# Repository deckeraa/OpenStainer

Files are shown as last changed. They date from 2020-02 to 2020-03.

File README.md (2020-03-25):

# slide-stainer

The OpenStainer is open-source, open-hardware automated slide stainer for laboratory use (e.g. histology, nanotech research).

Note: the OpenStainer is not yet released. This message will be removed from the README when the project has shipped it's 1.0 version.

## Development Mode

### Run application:
Boot an RT-PREEMPT-patched Linux distro on a Raspberry Pi.
The RT-PREEMPT patch is needed for smooth motor control since the stepper control signal is generated directly on the Pi.

To build the Rust web server (./src/main.rs),
you'll need to use Nightly Rust, due to some crates (namely Rocket) that require it:
```
rustup override set nightly
```

Then build and run the binary.
The binary must be run with sudoer priveleges since it sets thread priority to real-time for purposes of motion control.
```
cargo build && sudo ./target/debug/rmrm
```

Finally, start up the Clojurescript front-end

```
lein figwheel dev devcards
```

Figwheel will automatically push cljs changes to the browser.

Wait a bit, then browse to [http://localhost:3449](http://localhost:3449).

## Configuring the software to auto-start on Pi boot
In /etc/rc.local, place the following:
```
su -l pi /home/pi/code/slide-stainer/run.sh &
```

In /etc/xdg/lxsession/LXDE-pi/autostart, place the following:
```
chromium-browser http://localhost:8000/index.html --kiosk
```

## Production Build

```
lein clean
lein cljsbuild once min
```

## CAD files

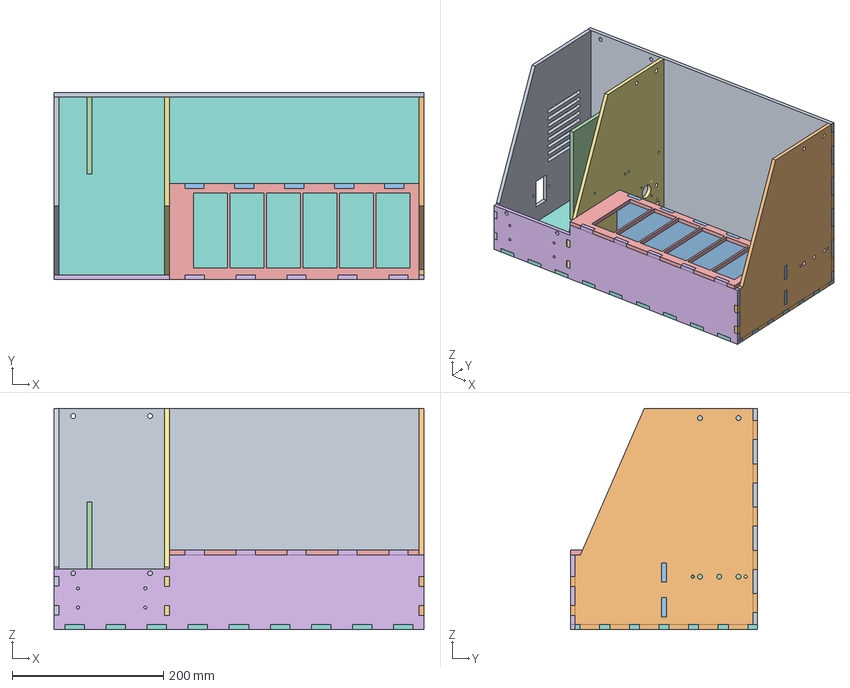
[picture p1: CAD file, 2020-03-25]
cad/frame_cut.FCStd
489.0 x 247.7 x 292.1 mm
left_plate001_tab
panel_with_rod001_tab
jar_holder_support001_tab
power_supply_retainer001_tab
jar_holder_1x007_tab
front_low_panel001_tab
panel_with_motor001_tab
bottom_panel001_tab
back_panel_body001_tab

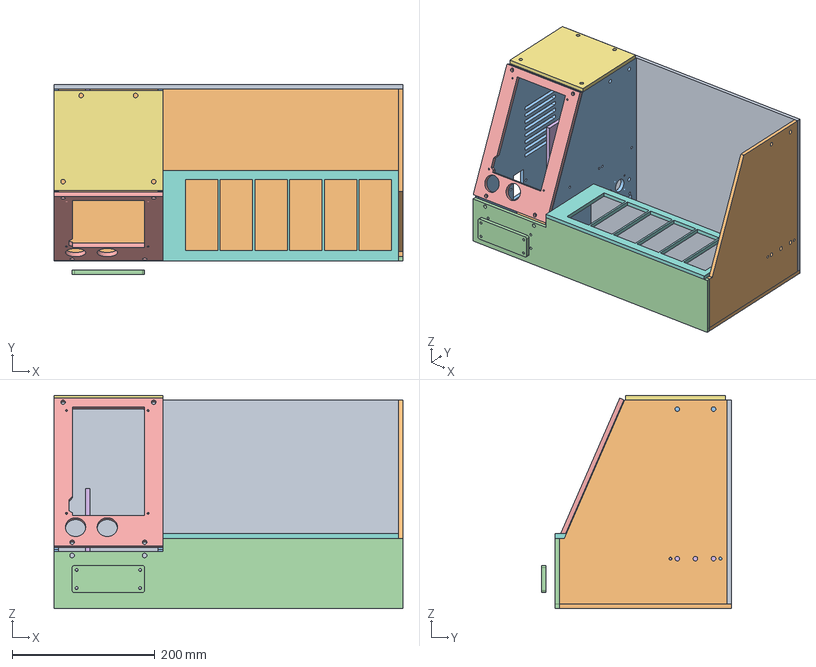
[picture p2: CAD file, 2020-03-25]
cad/frame_precut.FCStd
489.0 x 266.7 x 298.5 mm
back_panel_body
bottom_panel
panel_with_motor
front_low_panel
screen_panel_body
power_supply_retainer
cabinet_roof
jar_holder_1x6
jar_holder_support
panel_with_rod
left_plate
logo_plate

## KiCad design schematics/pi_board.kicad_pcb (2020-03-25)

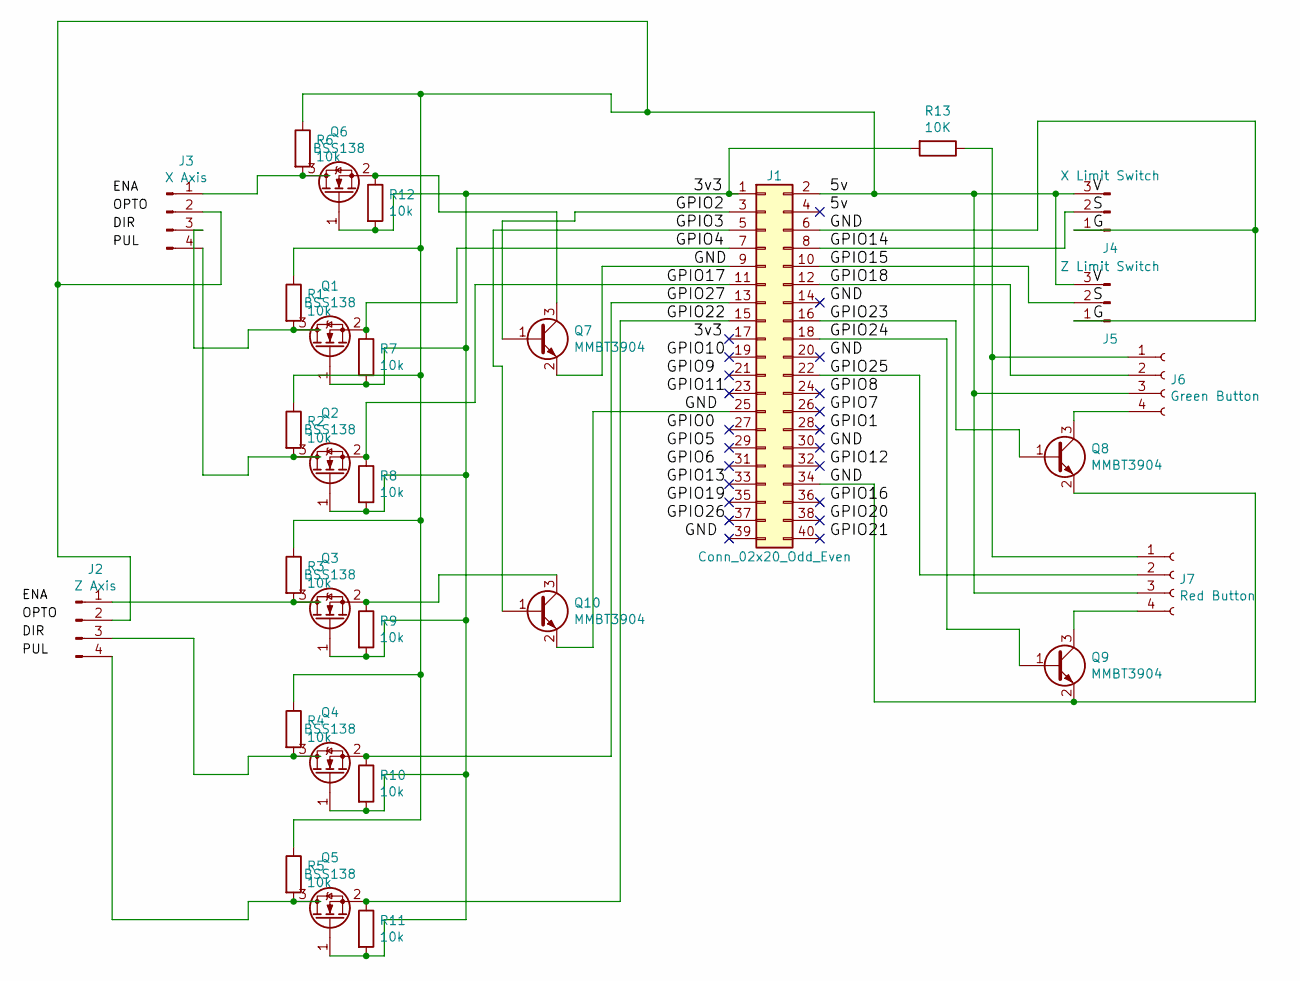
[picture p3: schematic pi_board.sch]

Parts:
J1: Conn_02x20_Odd_Even; PinHeader_2x20_P2.54mm_Vertical
J2: Z Axis; PinHeader_1x04_P2.54mm_Vertical
J3: X Axis; PinHeader_1x04_P2.54mm_Vertical
J4: X Limit Switch; PinHeader_1x03_P2.54mm_Vertical
J5: Z Limit Switch; PinHeader_1x03_P2.54mm_Vertical
J6: Green Button; PinHeader_1x04_P2.54mm_Vertical
J7: Red Button; PinHeader_1x04_P2.54mm_Vertical
Q1, Q2, Q3, Q4, Q5, Q6: BSS138; SOT-23
Q7, Q8, Q9, Q10: MMBT3904; SOT-23
R1, R2, R3, R4, R5, R6, R7, R8, R9, R10, R11, R12: 10k; R_1206_3216Metric_Pad1.42x1.75mm_HandSolder
R13: 10K; R_1206_3216Metric_Pad1.42x1.75mm_HandSolder

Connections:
/3v3: J1.1, Q1.1 (G), Q2.1 (G), Q3.1 (G), Q4.1 (G), Q5.1 (G), Q6.1 (G), R7.2, R8.2, R9.2, R10.2, R11.2, R12.2, R13.2
/5v: J1.2, J2.2, J3.2, J4.3, J5.3, J6.3, J7.3, R1.1, R2.1, R3.1, R4.1, R5.1, R6.1
/G: J1.6, J1.9, J1.25, J1.34, J4.1, J5.1, Q7.2 (E), Q8.2 (E), Q9.2 (E), Q10.2 (E)
/GPIO2: J1.3, Q7.1 (B)
/GPIO3: J1.5, Q10.1 (B)
/GPIO4: J1.7, Q1.2 (S), R7.1
/GPIO14: J1.8, J4.2
/GPIO15: J1.10, J5.2
/GPIO17: J1.11, Q2.2 (S), R8.1
/GPIO18: J1.12, J6.2
/GPIO22: J1.15, Q5.2 (S), R11.1
/GPIO23: J1.16, Q8.1 (B)
/GPIO24: J1.18, Q9.1 (B)
/GPIO25: J1.22, J7.2
/GPIO27: J1.13, Q4.2 (S), R10.1
unnamed: J2.1, Q3.3 (D), R3.2
unnamed: J2.3, Q4.3 (D), R4.2
unnamed: J2.4, Q5.3 (D), R5.2
unnamed: J3.1, Q6.3 (D), R6.2
unnamed: J3.3, Q1.3 (D), R1.2
unnamed: J3.4, Q2.3 (D), R2.2
unnamed: J6.1, J7.1, R13.1
unnamed: J6.4, Q8.3 (C)
unnamed: J7.4, Q9.3 (C)
unnamed: Q6.2 (S), Q7.3 (C), R12.1
unnamed: Q3.2 (S), Q10.3 (C), R9.1

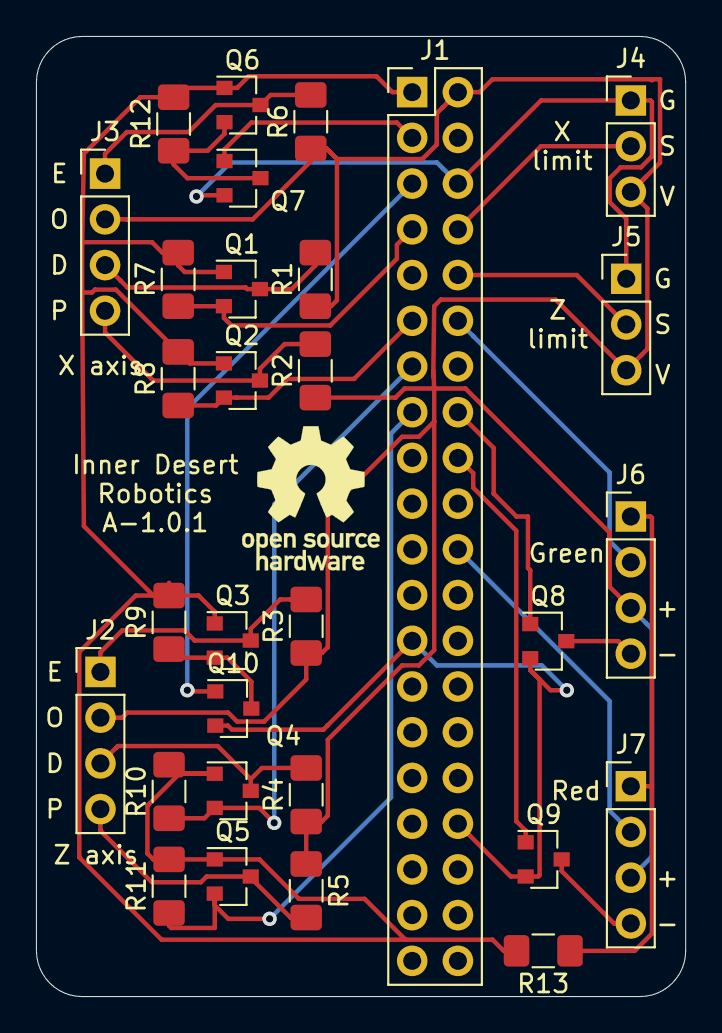
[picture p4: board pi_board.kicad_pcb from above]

Board: 2 copper layers, 36.1 x 53.3 mm, 30 parts (0 on the bottom side), 26 nets.

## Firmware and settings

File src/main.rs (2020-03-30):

#![feature(proc_macro_hygiene, decl_macro)]

#[macro_use]
extern crate rocket;

mod structs_and_consts;
mod graphql;
mod motion;
mod couchdb;

use gpio::{GpioIn, GpioOut};
use rocket::http::{Method};
use rocket::State;
use std::sync::Mutex;
use std::convert::TryInto;
use std::{thread, time};
use juniper::{FieldResult};
use rocket_contrib::serve::StaticFiles;
use rocket_cors::{AllowedHeaders, AllowedOrigins};
use std::time::{Instant};
use std::sync::atomic::Ordering;
use std::sync::atomic::*;
use std::process::Command;
pub use crate::structs_and_consts::*;
pub use crate::graphql::*;
pub use crate::motion::*;
pub use crate::couchdb::*;

#[rocket::post("/pause_procedure")]
fn pause_procedure(pes: State<ProcedureExecutionState>) -> String {
    let pes = pes.inner();
    pes.atm.store(ProcedureExecutionStateEnum::Paused, Ordering::Relaxed);
    format! {"/pause {:?}", pes.atm.load(Ordering::Relaxed)}
}

#[rocket::post("/resume_procedure")]
fn resume_procedure(pes: State<ProcedureExecutionState>) -> String {
    let pes = pes.inner();
    pes.atm.store(ProcedureExecutionStateEnum::Running, Ordering::Relaxed);
    format! {"/pause {:?}", pes.atm.load(Ordering::Relaxed)}
}

#[rocket::post("/stop_procedure")]
fn stop_procedure(pes: State<ProcedureExecutionState>) -> String {
    let pes = pes.inner();
    pes.atm.store(ProcedureExecutionStateEnum::Stopped, Ordering::Relaxed);
    format! {"/pause {:?}", pes.atm.load(Ordering::Relaxed)}
}

#[rocket::get("/read_procedure_status")]
fn read_procedure_status(pes: State<ProcedureExecutionState>) -> String {
    let pes = pes.inner();
    format! {"/read {:?}", pes.atm.load(Ordering::Relaxed)}
}

#[rocket::get("/seconds_remaining")]
fn seconds_remaining(pes: State<ProcedureExecutionState>) -> String {
    let pes = pes.inner();
    format! {"{}", pes.seconds_remaining.load(Ordering::Relaxed)}
}

#[post("/home")]
fn home_handler(pi_state: State<SharedPi>, pes: State<ProcedureExecutionState>) -> String {
    let pi_mutex = &mut pi_state.inner();
    let pi = &mut *pi_mutex.lock().unwrap();
    let pes = pes.inner();
    let ret = home(pi, Some(pes));
    format! {"{:?}",ret}
}

#[post("/run_procedure/<id>")]
fn run_procedure(pi_state: State<SharedPi>, pes: State<ProcedureExecutionState>, id: String) -> String {
    let pes = pes.inner();
    println!("In run_procedure, pes: {:?}",pes.atm.load(Ordering::Relaxed));
    if pes.atm.load(Ordering::Relaxed) == ProcedureExecutionStateEnum::Running {
	println!("Already running a procedure. Exiting.");
	return "Already running a procedure. Exiting.".to_string();
    }

    let pi_mutex = &mut pi_state.inner();

    pes.atm.store(ProcedureExecutionStateEnum::Running, Ordering::Relaxed);

    // load the procedure
    let proc : FieldResult<Procedure> = procedure_by_id(id);
    if proc.is_err() { return format! {"Couldn't find procedure with that ID."}; }
    let mut proc = proc.unwrap();

    {
	let pi = &mut *pi_mutex.lock().unwrap();
	pi.current_procedure = Some(proc.clone());
	// initialize the run status
	pi.run_status = Some(ProcedureRunStatus {
	    current_procedure_step_number : 0,
	    current_cycle_number: 0,
	    run_state: ProcedureExecutionStateEnum::Running,
	});
	pi.red_light.set_high().expect("Couldn't turn on estop light.");
    }

    let num_repeats = match proc.repeat {
	Some(v) => v,
	None => 1
    };
    // loop over repeats
    for repeat_num in 0..num_repeats {
	println!("Repeat #: {}",num_repeats);
	// loop over steps
	println!("proc.procedure_steps: {:?}", proc.procedure_steps);
	for (index,step) in proc.procedure_steps.iter().enumerate() {
	    if pes.atm.load(Ordering::Relaxed) == ProcedureExecutionStateEnum::Stopped {
		break; // end the procedure if the user stopped it
	    }
	    println!("Trying to grab the lock.");
	    // grab the lock
	    {
		let pi = &mut *pi_mutex.lock().unwrap();
		let run_status = pi.run_status.as_mut().unwrap();
		run_status.current_cycle_number = repeat_num + 1;
		run_status.current_procedure_step_number = (index + 1).try_into().unwrap();
		//pi.run_status.current_procedure_step_number = pi.run_status.current_procedure_step_number
		println!("Step: {:?}",step);
		// move to the jar
		println!("Entering loop B");
		loop {
		    let state = pes.atm.load(Ordering::Relaxed);
		    if state == ProcedureExecutionStateEnum::Running {
			println!("============== Running move_to_jar {:?} ", step.jar_number);
			pi.green_light.set_low().expect("Couldn't turn green light off");
			pi.red_light.set_high().expect("Couldn't turn red light back on");
			let ret = move_to_jar( pi, step.jar_number, Some(&pes) );
			if ret == MoveResult::MovedFullDistance {
			    break;
			}
			if ret == MoveResult::HitLimitSwitch {
			    println!("move_to_jar hit a limit switch!");
			    pes.atm.store(ProcedureExecutionStateEnum::Paused, Ordering::Relaxed);
			    pi.green_light.set_high().expect("Couldn't turn green light on");
			    pi.red_light.set_low().expect("Couldn't turn red light off");
			}
		    }
		    if state == ProcedureExecutionStateEnum::Stopped {
			break; // end the procedure if the user stopped it
		    }
		    // note: don't replace "pes.atm.load(Ordering::Relaxed)" with "state" in the below line.
		    // This uses updates to the state in move_to_jar to perform logic."
		    if pes.atm.load(Ordering::Relaxed) == ProcedureExecutionStateEnum::Paused {
			pi.green_light.set_high().expect("Couldn't turn green light on");
			pi.red_light.set_low().expect("Couldn't turn red light off");
			if bool::from(pi.green_button.read_value().unwrap()) {
			    pes.atm.store(ProcedureExecutionStateEnum::Running, Ordering::Relaxed);
			    pi.green_light.set_low().expect("Couldn't turn green light off");
			    pi.red_light.set_high().expect("Couldn't turn red light back on");
			}
		    }
		    thread::sleep(time::Duration::from_millis(10));
		}
	    }
	    println!("Exited loop B");

	    //pi.run_status.current_procedure_step_start_instant = Instant::now();
	    let mut start_instant = Instant::now();
	    let mut us_remaining : u128 = (step.time_in_seconds * 1000 * 1000).try_into().unwrap();

	    // sleep until it's time to move again
	    println!("Entering loop C");
	    while us_remaining > 0 {
		if pes.atm.load(Ordering::Relaxed) == ProcedureExecutionStateEnum::Running {
		    // update the timer controls
		    let elapsed_us = start_instant.elapsed().as_micros();
		    start_instant = Instant::now();
		    if elapsed_us > us_remaining { // avoid attempts to subtract with overflow
			us_remaining = 0;
		    }
		    else {
			us_remaining = us_remaining - elapsed_us;
		    }

		    // update the PES to inform the client how many seconds are remaining
		    pes.seconds_remaining.store((us_remaining / (1000 * 1000)).try_into().unwrap(), Ordering::Relaxed);
		}
		// grab the lock
		{
		    let pi = &mut *pi_mutex.lock().unwrap();
		    // check stop button
		    if bool::from(pi.estop.read_value().unwrap()) {
			pes.atm.store(ProcedureExecutionStateEnum::Paused, Ordering::Relaxed);
		    }
		    let state = pes.atm.load(Ordering::Relaxed);
		    if state == ProcedureExecutionStateEnum::Stopped {
			break;
		    }
		    if state == ProcedureExecutionStateEnum::Paused {
			// handle run/pause buttons
			pi.green_light.set_high().expect("Couldn't turn green light on");
			pi.red_light.set_low().expect("Couldn't turn red light off");
			if bool::from(pi.green_button.read_value().unwrap()) {
			    pes.atm.store(ProcedureExecutionStateEnum::Running, Ordering::Relaxed);
			    pi.green_light.set_low().expect("Couldn't turn green light off");
			    pi.red_light.set_high().expect("Couldn't turn red light back on");
			    start_instant = Instant::now();
			}
		    }
		}
		thread::sleep(time::Duration::from_millis(20));
	    }
	    println!("Exited loop C");
	}
    }

    // End of procedure, so move to the up position
    {
	let pi = &mut *pi_mutex.lock().unwrap();
	loop {
	    let state = pes.atm.load(Ordering::Relaxed);
	    if state == ProcedureExecutionStateEnum::Running ||
		state == ProcedureExecutionStateEnum::Stopped
	    {
		println!("============== Running move_to_up ");
		//let ret = move_to_jar( pi, step.jar_number, Some(&pes) );
		pi.green_light.set_low().expect("Couldn't turn green light off");
		pi.red_light.set_high().expect("Couldn't turn red light back on");
		let ret = move_to_up_position( pi, Some(&pes), true);
		if ret == MoveResult::MovedFullDistance {
		    break;
		}
	    }
	    if pes.atm.load(Ordering::Relaxed) == ProcedureExecutionStateEnum::Paused {
		pi.green_light.set_high().expect("Couldn't turn green light on");
		pi.red_light.set_low().expect("Couldn't turn red light off");
		if bool::from(pi.green_button.read_value().unwrap()) {
		    pes.atm.store(ProcedureExecutionStateEnum::Running, Ordering::Relaxed);
		    pi.green_light.set_low().expect("Couldn't turn green light off");
		    pi.red_light.set_high().expect("Couldn't turn red light back on");
		}
	    }
	    thread::sleep(time::Duration::from_millis(10));
	}
	
	pi.run_status = None;
	pi.red_light.set_low().expect("Couldn't turn off estop light.");

	pes.atm.store(ProcedureExecutionStateEnum::Completed, Ordering::Relaxed);
	let inc_result : FieldResult<Procedure> = increment_run_count(&mut proc);
	if inc_result.is_ok() {
	    pi.current_procedure = Some(inc_result.unwrap());
	}
    }
    format! {"run_procedure completed"}
}

#[post("/move_by_pulses/<axis>/<forward>/<pulses>")]
fn move_by_pulses(
    pi_state: State<SharedPi>,
    pes: State<ProcedureExecutionState>,
    axis: AxisDirection,
    forward: bool,
    pulses: PulseCount,
) -> String {
    let pi_mutex = &mut pi_state.inner();
    let pi = &mut *pi_mutex.lock().unwrap();
    let pes = pes.inner();
    let ret = move_steps(pi, axis, forward, pulses, false, Some(pes), false);
    format! {"{:?}",ret}
}

#[post("/move_by_inches/<axis>/<forward>/<inches>")]
fn move_by_inches(pi_state: State<SharedPi>, pes: State<ProcedureExecutionState>, axis: AxisDirection, forward: bool, inches: Inch) -> String {
    let pi_mutex = &mut pi_state.inner();
    let pi = &mut *pi_mutex.lock().unwrap();
    let stepper = get_stepper(pi, &axis);
    let pulses = inches_to_pulses(inches, stepper);
    let pes = pes.inner();
    let ret = move_steps(pi, axis, forward, pulses, false, Some(pes), false);
    format! {"{:?}",ret}
}


#[post("/move_to_pos/<axis>/<inches>")]
fn move_to_pos_handler(pi_state: State<SharedPi>, pes: State<ProcedureExecutionState>, axis: AxisDirection, inches: Inch) -> String {
    let pi_mutex = &mut pi_state.inner();
    let pi = &mut *pi_mutex.lock().unwrap();
    let pes = pes.inner();
    let ret = move_to_pos(pi, axis, inches, Some(pes), false);
    format! {"{:?}",ret}
}

#[post("/move_to_up_position")]
fn move_to_up_position_handler(pi_state: State<SharedPi>, pes: State<ProcedureExecutionState>) -> String {
    let pi_mutex = &mut pi_state.inner();
    let pi = &mut *pi_mutex.lock().unwrap();
    let pes = pes.inner();
    let ret = move_to_up_position(pi, Some(pes), true); // skip_soft_estop_check is set to true so that the user can manually raise the rack while paused
    format! {"{:?}",ret}
}

#[post("/move_to_down_position")]
fn move_to_down_position_handler(pi_state: State<SharedPi>, pes: State<ProcedureExecutionState>) -> String {
    let pi_mutex = &mut pi_state.inner();
    let pi = &mut *pi_mutex.lock().unwrap();
    let pes = pes.inner();
    let ret = move_to_down_position(pi, Some(pes), true); // skip_soft_estop_check is set to true so that the user can manually lower the rack while paused
    format! {"{:?}",ret}
}

#[post("/move_to_left_position")]
fn move_to_left_position_handler(pi_state: State<SharedPi>, pes: State<ProcedureExecutionState>) -> String {
    let pi_mutex = &mut pi_state.inner();
    let pi = &mut *pi_mutex.lock().unwrap();
    let pes = pes.inner();
    let ret = move_to_left_position(pi, Some(pes));
    format! {"{:?}",ret}
}

#[post("/move_to_jar/<jar_number>")]
fn move_to_jar_handler(pi_state: State<SharedPi>, pes: State<ProcedureExecutionState>, jar_number: i32) -> String {
    let pi_mutex = &mut pi_state.inner();
    let pes = pes.inner();
    let pi = &mut *pi_mutex.lock().unwrap();
    println!("0.1: {}", jar_number);
    let ret = move_to_jar(pi, jar_number, Some(pes));
    format! {"{:?}",ret}
}

#[get("/pos/<axis>")]
fn pos(pi: State<SharedPi>, axis: AxisDirection) -> String {
    let pi = &mut *pi.inner().lock().unwrap();
    let stepper = match axis {
        AxisDirection::X => &mut pi.stepper_x,
        AxisDirection::Z => &mut pi.stepper_z,
    };
    match stepper.pos {
        Some(v) => format!("{}", pulses_to_inches(v, stepper)),
        None => "Not homed".to_string(),
    }
}

#[get("/play_note?<note_hz>&<duration_ms>&<forward>")]
fn play_note(pi_state: State<SharedPi>, note_hz: f64, duration_ms: u64, forward: bool) -> String {
    let pi_mutex = &mut pi_state.inner();
    let pi = &mut *pi_mutex.lock().unwrap();
    crate::motion::play_note(pi, AxisDirection::X, forward, note_hz, duration_ms, None);
    "Played note".to_string()
}

#[get("/move_turns_at_freq?<hz>&<forward>&<turns>")]
fn move_turns_at_freq(pi_state: State<SharedPi>, hz: f64, forward: bool, turns :u64) -> String {
    let pi_mutex = &mut pi_state.inner();
    let pi = &mut *pi_mutex.lock().unwrap();
    crate::motion::move_turns_at_freq(pi, AxisDirection::X, forward, hz, turns);
    "move_turns_at_freq complete".to_string()
}

#[get("/run_motor_test?<forward>&<acceleration_constant>&<number_of_turns>")]
fn run_motor_test(pi_state: State<SharedPi>, forward: bool, acceleration_constant : f64, number_of_turns: u64) -> String {
    let pi_mutex = &mut pi_state.inner();
    let pi = &mut *pi_mutex.lock().unwrap();
    return crate::motion::run_motor_test(pi, AxisDirection::X, forward, acceleration_constant, number_of_turns);
}

// This runs a script that closes the current chromium-browser session (running in kiosk mode)
// and starts a new one not in kiosk mode. This is useful for when a user wishes to access the underlying Raspian OS
// capabilites of the Pi.
#[post("/exit_kiosk_mode")]
fn exit_kiosk_mode() -> String {
    let mut command = Command::new("./exit_kiosk_mode.sh");
    let result = match command.status() {
	Ok(r) => r.to_string(),
	Err(e) => e.to_string(),
    };
    format!("{:?} {}",command, result)
}

fn main() {
    let shared_pi = Mutex::new(Pi {
        estop: gpio::sysfs::SysFsGpioInput::open(25).unwrap(),
	green_button: gpio::sysfs::SysFsGpioInput::open(18).unwrap(),
	red_light: gpio::sysfs::SysFsGpioOutput::open(24).unwrap(),
	green_light: gpio::sysfs::SysFsGpioOutput::open(23).unwrap(),
        stepper_x: Stepper {
            ena: gpio::sysfs::SysFsGpioOutput::open(2).unwrap(),
            dir: gpio::sysfs::SysFsGpioOutput::open(4).unwrap(),
            pul: gpio::sysfs::SysFsGpioOutput::open(17).unwrap(),
            limit_switch_low: Some(gpio::sysfs::SysFsGpioInput::open(14).unwrap()),
            limit_switch_high: None,
            pos: None,
            position_limit: 10.0,
            pulses_per_revolution: 4000,
            travel_distance_per_turn: 0.063,
        },
        stepper_z: Stepper {
            ena: gpio::sysfs::SysFsGpioOutput::open(3).unwrap(),
            dir: gpio::sysfs::SysFsGpioOutput::open(27).unwrap(),
            pul: gpio::sysfs::SysFsGpioOutput::open(22).unwrap(),
            limit_switch_low: None,
            limit_switch_high: Some(gpio::sysfs::SysFsGpioInput::open(15).unwrap()),
            pos: None,
            position_limit: 3.75,
            pulses_per_revolution: 4000,
            travel_distance_per_turn: 0.063,
        },
	current_procedure: None,
	run_status: None,
    });

    let atm : AtomicProcedureExecutionStateEnum = AtomicProcedureExecutionStateEnum::new(ProcedureExecutionStateEnum::NotStarted);
    let pes : ProcedureExecutionState = ProcedureExecutionState { atm: atm, seconds_remaining: AtomicU64::new(0)};

    {
	// initialize enable pins (this is needed since the logic is reversed since it's behind
	// a transistor. The reason it is behind a transistor is because the pins are automatically
	// set to pulled-up inputs on Pi boot.
	let pi = &mut *shared_pi.lock().unwrap();
	pi.stepper_x.ena.set_high().expect("Couldn't set enable pin"); // high is low since it's behind a transistor
	pi.stepper_z.ena.set_high().expect("Couldn't set enable pin"); // high is low since it's behind a transistor
    }
    
    // set up CORS
    let allowed_origins = AllowedOrigins::all();
    let cors = rocket_cors::CorsOptions {
        allowed_origins,
        allowed_methods: vec![Method::Get, Method::Put, Method::Post, Method::Delete].into_iter().map(From::from).collect(),
        allowed_headers: AllowedHeaders::some(&["Authorization", "Accept","X-Requested-With","Content-Type","Cache-Control"]),
        allow_credentials: true,
        ..Default::default()
    }
    .to_cors().unwrap();

    rocket::ignite()
        .manage(shared_pi)
	.manage(Schema::new(Query, Mutation))
	.manage(pes)
        .mount(
            "/",
            routes![
                home_handler,
                pos,
                move_by_pulses,
                move_by_inches,
                move_to_pos_handler,
                move_to_up_position_handler,
                move_to_down_position_handler,
                move_to_left_position_handler,
                move_to_jar_handler,
		graphiql,
		post_graphql_handler,
		run_procedure,
		pause_procedure,
		resume_procedure,
		stop_procedure,
		read_procedure_status,
		seconds_remaining,
		exit_kiosk_mode,
		play_note,
		move_turns_at_freq,
		run_motor_test,
            ],)
	.mount("/",StaticFiles::from("./resources/public/"))
	.attach(cors)
        .launch();
}

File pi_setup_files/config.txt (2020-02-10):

#
# This file needs to be /boot/config.txt
#
# For more options and information see
# http://rpf.io/configtxt
# Some settings may impact device functionality. See link above for details
kernel=kernel7_rt.img

boot_delay=0

# uncomment if you get no picture on HDMI for a default "safe" mode
#hdmi_safe=1

# uncomment this if your display has a black border of unused pixels visible
# and your display can output without overscan
#disable_overscan=1

# uncomment the following to adjust overscan. Use positive numbers if console
# goes off screen, and negative if there is too much border
#overscan_left=16
#overscan_right=16
#overscan_top=16
#overscan_bottom=16

# uncomment to force a console size. By default it will be display's size minus
# overscan.
#framebuffer_width=1280
#framebuffer_height=720

# uncomment if hdmi display is not detected and composite is being output
#hdmi_force_hotplug=1

# uncomment to force a specific HDMI mode (this will force VGA)
#hdmi_group=1
#hdmi_mode=1

# uncomment to force a HDMI mode rather than DVI. This can make audio work in
# DMT (computer monitor) modes
#hdmi_drive=2

# uncomment to increase signal to HDMI, if you have interference, blanking, or
# no display
#config_hdmi_boost=4

# uncomment for composite PAL
#sdtv_mode=2

#uncomment to overclock the arm. 700 MHz is the default.
#arm_freq=800

# Uncomment some or all of these to enable the optional hardware interfaces
#dtparam=i2c_arm=on
#dtparam=i2s=on
#dtparam=spi=on

# Uncomment this to enable the lirc-rpi module
#dtoverlay=lirc-rpi

# Additional overlays and parameters are documented /boot/overlays/README

# Enable audio (loads snd_bcm2835)
dtparam=audio=on

[pi4]
# Enable DRM VC4 V3D driver on top of the dispmanx display stack
dtoverlay=vc4-fkms-v3d
max_framebuffers=2

[all]
#dtoverlay=vc4-fkms-v3d

# NOOBS Auto-generated Settings:
hdmi_force_hotplug=1

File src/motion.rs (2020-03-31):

pub use crate::structs_and_consts::*;
pub use crate::couchdb::*;

use gpio::{GpioIn, GpioOut};
use std::{thread, time};
use thread_priority::*;
use std::sync::atomic::Ordering;
use std::convert::TryFrom;
use std::convert::TryInto;

// Converts inches to pulses for a given stepper's configuration
pub fn inches_to_pulses(inches: Inch, stepper: &Stepper) -> PulseCount {
    (stepper.pulses_per_revolution as f64 * inches / stepper.travel_distance_per_turn) as u64
}

// Converts pulses to inches for a given stepper's configuration
pub fn pulses_to_inches(pulses: PulseCount, stepper: &Stepper) -> Inch {
    pulses as f64 * stepper.travel_distance_per_turn / stepper.pulses_per_revolution as f64
}

// Generates an array of wait times to play a note for a given duration.
// If step_override has a value other than None, then the number of steps passed will be used
// rather than duration_ms to determine how long to play the note.
// This is mostly useful for analyzing the potential loss of steps while turning a stepper at a fixed frequency.
fn generate_note_times(note_hz: f64, duration_ms: u64, step_override: Option<u64>) -> Vec<std::time::Duration> {
    println!("note_hz before round {:?}", note_hz);
    let note_hz = note_hz.round() as u64;
    println!("note_hz after round {:?}", note_hz);
    let size = match step_override {
	Some(s) => s,
	None => note_hz * duration_ms / 1000,
    };
    let mut times = vec![time::Duration::from_nanos(0); size.try_into().unwrap()];
    if size == 0 {
        return times;
    }
    for i in 0..size {
	times[usize::try_from(i).unwrap()] = time::Duration::from_nanos(1_000_000_000 / note_hz);
    }
    times
}

// Generates an array of wait times to be used to drive the stepper.
// Size is the number of steps to move the stepper, and a is a constant acceleration to apply.
// a is in Hz/sec BUT it has a hidden constant coefficient based upon the stepper driver settings.
// E.g. if you set the stepper driver to 4000 steps/rev, then a is going to need to be different than if
// it was set to 1600 steps/rev.
fn generate_wait_times(
    size: u64,
    a: f64,
) -> Vec<std::time::Duration> {
    let size = size + 1; // we generate one more tmie than we need for an intermediate array, and then
    // put it in an array that's the right size.
    let mut times = vec![time::Duration::from_nanos(0); size.try_into().unwrap()];

    // We fill up the array with times halfway through and then mirror it to produce the deceleration ramp.
    let halfway = size / 2;
    for i in 1..halfway + 2 {
	// If we want a constant acceleration, then given steps y, time t and acceleration a, acceleration is
	// (d^2y / dt^2) = a
	// Integrating gives us velocity:
	// dy/dt = at
	// (For our application we don't care about the +C term resulting from integration).
	// Integrating once again gives us:
	// y = (1/2)at^2
	// When driving a stepper, we have to provide a signal for each pulse.
	// Thus, we can't pick y values based on t, instead we need to find t for values y = 1,2,3,4,5,6 etc.
	// Sovled for t: t = sqrt(2y/a).
	// (We don't care about the negative root since negative t values are nonsensical for our application).
	let calculated_time : f64 = (1_000_000_000.0/2.0) * (2.0/1.0 as f64).sqrt() * (i as f64 / a).sqrt();
	let mut selected_time = time::Duration::from_nanos(calculated_time.round() as u64);
	if selected_time < time::Duration::from_micros(5) {
	    selected_time = time::Duration::from_micros(5); // minimum size of the signal supported by the stepper driver
	}
        times[usize::try_from(i).unwrap() - 1] = selected_time;
    }
    // Now mirror the array ot produce the deceleration ramp
    for i in halfway+1..size {
        times[usize::try_from(i).unwrap()] = times[usize::try_from(size - i).unwrap()];
    }

    // now go through and calculate the actual wait time: (t_n+1 - t_n)/2
    // The array above gives us absolute times at which point steps need to occur, this gives us the distance
    // between times for use in our sleep() function when in the actual motor driving loop.
    // The 2 is in there because each pulse is divided equally into time with the signal HIGH and LOW.
    let mut wait_times = vec![time::Duration::from_nanos(0); size.try_into().unwrap()];
    for i in 1..halfway + 1{
	let t_b = times[usize::try_from(i).unwrap()];
	let t_a = if i == 0 { time::Duration::from_nanos(0) } else { times[usize::try_from(i-1).unwrap()] };
	wait_times[usize::try_from(i).unwrap()] = (t_b - t_a) / 2;
    }
    for i in halfway+1..size {
         wait_times[usize::try_from(i).unwrap()] = wait_times[usize::try_from(size - i).unwrap()];
    }
    wait_times.remove(0); // the first element is always 0 s, (since we start at index 1) so taking that one out.
    return wait_times;
}
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

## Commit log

2019-11-28 Basic LED blinking via REST.
2019-11-29 Basic html button that blinks an LED.
2019-11-29 Hook up web server to client, make two buttons to blink lines 17 and 18.
2019-11-30 Add pin controls and pulse controls. Get stepper spinning smoothly. Still figuring out how the DIR pin works.
2019-12-25 Logic switches for the level switcher and some style updates.
2020-01-02 Rename project from test-reagent to slide-stainer.
2020-01-03 Add support for reading the board value of pins.
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2020-01-03 Add handling for returning pin number using the pin setup index. Add support for logical_value.
2020-01-03 Added support to use the pin configuration in init-pins.
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2020-01-09 Init pins in the reolved-pin-by-id function (when needed) and introduce a function to handling incoming tag names.
2020-01-10 WIP make some changes to try to get the pin miutation returning the right data.
2020-01-16 Add in stepperX config and rename the old stepperX to stepperZ.
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2020-01-19 Add graphql-click-handler abstraction and a button to clean up pins, as well as the init-watcher function.
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2020-01-21 Init watcher using a transformed pin defs rather than a hard-coded map.
2020-01-21 Stop axis motion when limit switch is hit.
2020-01-21 Add bounds-setting code in move-to-position for when the limit switch gets hit.
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2020-01-28 Switch to passing reagent atoms through the program creation components.
2020-01-28 Add ability to switch substance listed for a step (WIP).
2020-01-28 Create jar-selector to determine which jar to move to in the case of identical substances.
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2020-01-30 Add support for tracking osk input elements and inserting characters at the current cursor location. Space and Backspace still not supported for cursor input.
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2020-01-30 Fix Reagent warnings for the pins-graphql-control
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2020-02-05 Add estop to pin defs and for both axis's direction control.
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2020-02-05 Add homing endpoint and button. Homing implementation TBD.
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2020-02-08 Spend less time waiting before spinning up motors
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2020-02-10 Add in a stop to jar movement when the limit switch is triggered unexpectedly. WIP, still need to get the lock cleaned up and require re-homing.
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2020-02-10 Add pi_setup_files/config.txt
    [config.txt]
2020-02-11 Implement round-trip to CouchDB and back for saving a procedure on the sample-program screen.
2020-02-11 Add a run button and switch run-program-by-name to run-program-by-id
2020-02-11 Update program save button to not clobber the atom when query fails.
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2020-02-12 WIP add current step number and step start time.
2020-02-12 back off a quarter inch in the up position so we're not constantly triggering the limit switch
2020-02-13 WIP: Switch run button to open up the run screen.
2020-02-13 Store the :current_procedure_step_number and use it in the procedure runs screen.
2020-02-13 Move current procedure status information to its own cursor.
2020-02-14 Make drop_motor_lock endpoint to reset the motor lock (for debugging & dev purposes)
2020-02-14 Add a button for dropping the motor lock.
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2020-02-14 Add a homing-failed alarm to prevent null exceptions when homing fails for whatever reason.
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2020-02-14 Move run-program-by-id into its own thread so that the graphql mutation query can return results before the run is physically completed.
2020-02-14 Start the program thread as the highest priority of the thread group.
2020-02-15 Update procedure-run's refresh button to use the factored-out refresh-fn.
2020-02-16 Switch the screen over to use the screen-cursor.
2020-02-16 Finishing switch over to :screen-stack for screen state management.
2020-02-17 Style buttons. Add home button to settings page.
2020-02-17 Make the settings home button perform the homing operation.
2020-02-17 Split out atoms.cljs. Also fix some reagent issues in settings.cljs
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2020-02-18 Save off the procedure-list in the app-state atom for blazing-fast page switches.
2020-02-18 Add heading and back button to procedure creation screen.
2020-02-18 Track how many times each procedure has been run.
2020-02-21 Comment out init-pins and make the home button hit up the real-time Rust micro-service.
2020-02-22 Add in a run button to the procedure run screen.
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2020-02-25 Produce run.sh to run everything in release mode. Also fixed a couple of issues (like underscores in file names) to enable release mode compiles.
2020-03-03 Add a backspace icon to the backspace button to save screen space.
2020-03-03 Add button:active style to give visual inidcation of button click.
2020-03-03 Make the onscreen-keyboard formatted correctly when in 'open' mode. (In devcards I was only testing it in 'closed' mode and needed to switch the 'open' mode from flex to inline-block.
2020-03-03 Remove led-button and pins-control-graphql (both of which are now unused) in core.cljs.
2020-03-03 Comment out the button bar at the top and add in a back button to the procedure run screen.
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2020-03-07 Make repeat Option<i32> and avoid serializing when null.
    [main.rs]
2020-03-09 Fix issue with parsing Juniper's GraphQL response.
    [main.rs]
2020-03-10 Add structs for current run status as well as a skeleton run_procedure handler.
2020-03-10 WIP. Fix typo to open up procedure_run screen after hitting the run button. Also update key names in procedure_run.cljs for the new Rust web server GraphQL API.
2020-03-12 WIP: Add in a GraphQL attribute for run_status, but it doesn't return the actual run status yet.
    [main.rs]
2020-03-12 Update settings screen to pull back coordinates correctly.
    [main.rs]
2020-03-12 Fix move-to-jar and move-slide-holder button.
    [main.rs]
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2020-03-19 Filter the substance selector options down to distinct values.
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2020-03-20 Have the delete button move back to the procedure selection screen. WIP, still need to make it update the list.
2020-03-20 Fix the deleteProcedure graphQL mutation (needed to pass _rev in the query string to couchDB in the DELETE call) and update the procedure-edit screen to use it. This fixes the issue where the main sc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
    [main.rs]
2020-03-24 Add schematics for A-1.0.1 board.
    [pi_board.kicad_pcb, pi_board.sch]
2020-03-24 Add frame CAD files.
    [frame_cut.FCStd, frame_precut.FCStd]
2020-03-25 Fix bug cause by extra unused argument being added to run-button in procedure_edit.cljs
2020-03-25 Add the lights for the buttons to the pi object, light up the estop button at the start of a procedure run and turn it off at the end, and fix a bug where hitting the estop during the firs tmvoe of a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
    [main.rs]
2020-03-26 Implement button-based paused and resume for most actions during a procedure run.
2020-03-26 Increase start_hz on pulse generation to eliminate noise.
    [main.rs]
2020-03-26 Prevent multiple procedures running at once.
    [main.rs]
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2020-03-27 Fix debug output on number of steps moved.
    [motion.rs]
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2020-03-28 Make the back gutton look like a button.
2020-03-28 Round button edges to make actionability visually consistent.
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2020-03-30 update pulses_per_revolution to 4000 to match driver settings.
2020-03-30 Pause procedure when z-limit switch is hit unexpectedly.
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2020-03-31 Hide the motor test and note playing controls from the settings screen.
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
